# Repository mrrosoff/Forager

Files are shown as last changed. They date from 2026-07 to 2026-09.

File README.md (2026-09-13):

# Forager

A hoary marmot that lives on a shelf. It is an e-ink tamagotchi in a small
3D-printed enclosure, and it is born the first time you power it on. You keep
it alive by feeding it real Pacific Northwest species, and what it offers you
depends on the season, the month, and the actual weather in Seattle.
Chanterelles show up after an autumn rain and not in March. Neglect it for
about a week and it dies.

Most of its life is deep sleep. Press ENTER, it wakes in a couple of seconds,
redraws the panel, and drops back to sleep after two minutes of being ignored.
A charge lasts a long time because the radio almost never runs.

<p align="center">
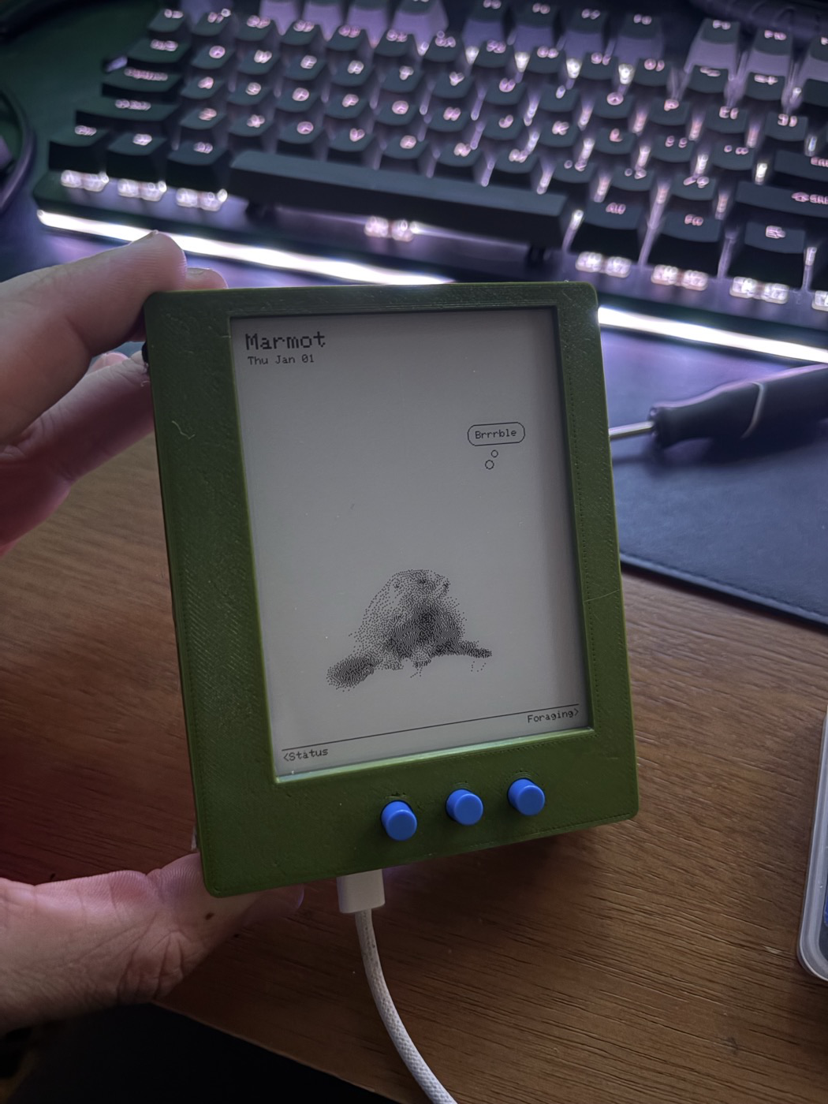
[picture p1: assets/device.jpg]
Forager: a hand-held e-ink marmot tamagotchi in a green 3D-printed enclosure
  
</p>

## Getting started

You need [PlatformIO](https://platformio.org/) and a WiFi network. Copy
`include/secrets.example.h` to `include/secrets.h` and list one or more
networks. On each sync it scans and joins whichever known network is
strongest, so you can leave both your house and your phone hotspot in there.

```cpp
static const WifiCred WIFI_NETWORKS[] = {
    {"home-ssid",  "home-pass"},
    {"phone-ssid", "hotspot-pass"},
};
```

Wire it up per the pin table in `include/config.h`, then build and flash over
the XIAO's USB-C port.

```sh
pio run              # build
pio run -t upload    # flash
pio device monitor   # serial monitor (115200)
```

esptool will claim it reset the board, but on USB-serial-JTAG it doesn't
actually start the app. Tap RESET after a flash.

There is no power switch, because the enclosure lost it. A brand new device
sits on a blank screen with its buttons armed until you press LEFT and RIGHT
together, which is the power-on gesture. That only ever happens once per
device. After that it runs the birth sequence and asks you to name the marmot.

Everything else configures itself. Weather comes from
[wttr.in](https://wttr.in/) and the clock from NTP, and neither one needs a
key.

## How it lives

**Four bars, three of them lethal.** Hunger, Happiness and Energy all decay
over roughly a week and will kill the marmot at either extreme. Curiosity is a
fourth bar that just sulks. Young marmots decay slower, which is the grace
period for figuring out what the buttons do. Every bar has something that
fills it. Eating and Snack Hunt cover Hunger, Marmot Says and resolved events
cover Happiness, Burrow Maze covers Energy, and the species games and
Discoveries cover Curiosity.

**It grows up on variety, not on time.** Baby to Juvenile to Adult is driven
by how many *distinct* species it has eaten, so a marmot fed the same
huckleberry every day stays a baby.

**Four views, LEFT and RIGHT to walk between them.** Minigames, Status, Main,
Foraging, with Main in the middle. Main is the marmot itself, along with its
mood, the weather and anything currently demanding attention. Foraging pages
through what is in season right now, sorted by what is actually worth picking,
and ENTER eats it. Status is the raw numbers for when you want to know exactly
how bad things are.

**Events happen while you're away.** Every six hours or so there's a chance
the next wake opens on a discovery, an animal sighting, a trail mishap, a
weather turn, a treasure, or an encounter, and it holds Main until you deal
with it. Playing with the thing regularly raises the odds, which is the point.

**Five minigames, all turn-based.** A panel refresh takes most of a second, so
nothing here can be scored on reflexes. Every game waits for you. Snack Hunt
and Marmot Says are there from birth, Forest Memory arrives at Juvenile,
Burrow Maze at Adult, and the Species Quiz once you've discovered 50 species.
Locked games aren't listed at all. Each one keeps a high score and gets a
one-time reveal screen when it unlocks.

**Winter is coming, specifically.** Snack Hunt's finds pile up in a stash
across days, and only the first run of each day counts, so you can't clear the
goal in one determined evening. The first December wake settles the books
against a 120-point goal. Falling short stings a little. It is not a second
way to kill the marmot.

The SETTINGS button (the one on the display module) gets you Achievements,
WiFi networks, Reset Game and Power Off.

## Hardware

| Part | Detail |
|---|---|
| MCU | Seeed XIAO ESP32S3, 8 MB flash, charges the cell over the same USB-C you flash through |
| Display | Waveshare 4.2" e-ink, 400×300 physical, mounted portrait for a 300×400 canvas |
| Buttons | 4× tactile, LEFT / RIGHT / ENTER, plus the display module's own KEY1 as SETTINGS |
| Battery | LiPo 3.7 V, soldered to BAT+/BAT- |

The XIAO breaks out exactly eleven GPIO and this needs exactly eleven, so
there is no spare and no room to change your mind. GPIO43/44 are neither
RTC-capable nor ADC, which rules them out for the three wake buttons and for
the battery divider, so they take display signals instead.

LEFT, RIGHT and ENTER are pulled down, read active-HIGH, and all three wake
the board out of deep sleep. SETTINGS rides the display board's KEY1, which is
wired to ground and therefore active-LOW, the opposite polarity from
everything else. It isn't a wake source, so Settings only exists once the
device is already awake.

One thing worth knowing before you debug the wrong end. This board will not
associate at the default 20 dBm. Scanning works fine the whole time and
reports a strong signal, because a scan only needs the receive path. Dropping
TX power to 8.5 dBm fixes it in about 1.6 seconds.

## Build, format, lint

```sh
pio run              # build
pio run -t upload    # flash
pio device monitor   # serial @ 115200

clang-format -i $(find src include -name '*.cpp' -o -name '*.h' | grep -v epd_official)
pio run -t compiledb    # then clang-tidy against src/, skipping epd_official/
```

Or just use the PlatformIO extension in VSCode, which
`.vscode/extensions.json` will offer you.

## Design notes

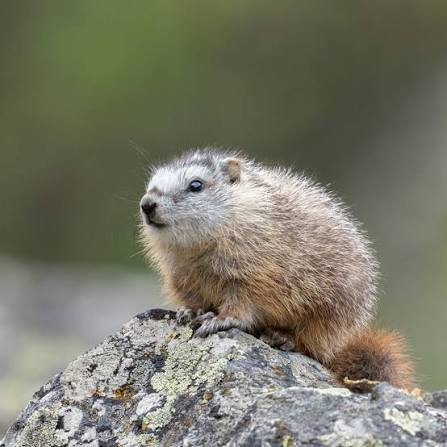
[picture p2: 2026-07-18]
assets/source_photos/marmot/juvenile3.jpg

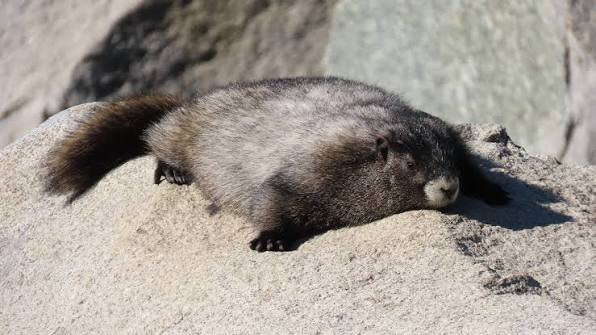
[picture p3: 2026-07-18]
assets/source_photos/marmot/variant15.jpg

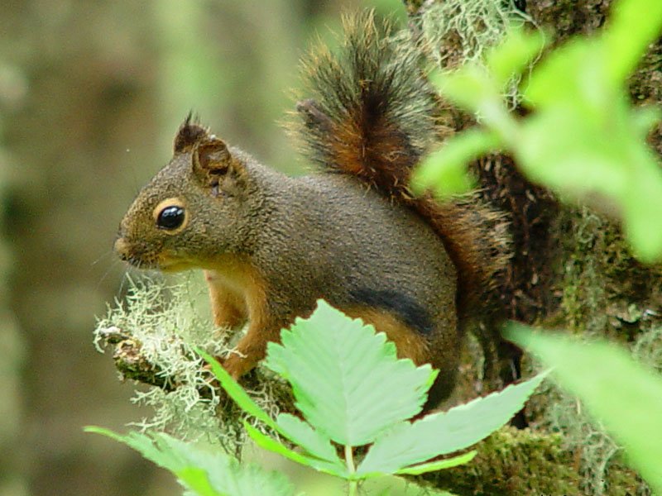
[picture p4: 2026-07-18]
assets/source_photos/animals/douglas_squirrel.jpg

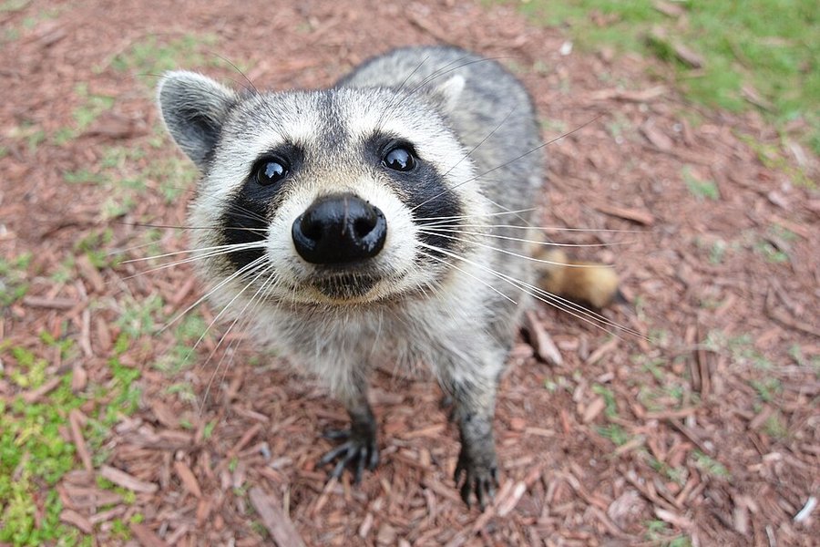
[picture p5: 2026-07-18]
assets/source_photos/animals/raccoon.jpg

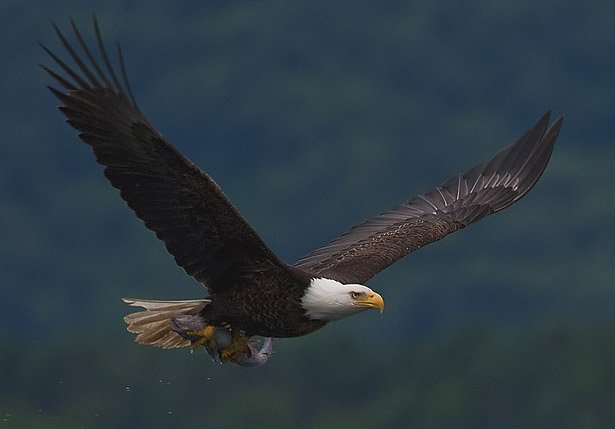
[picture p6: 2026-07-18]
assets/source_photos/animals/bald_eagle.jpg

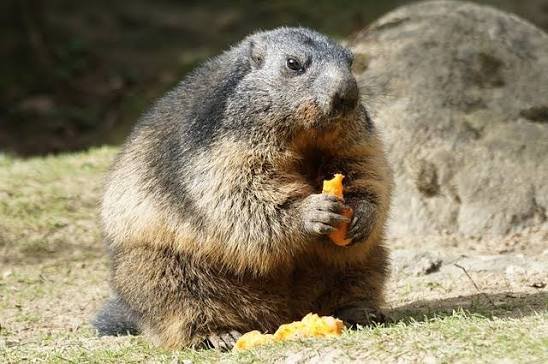
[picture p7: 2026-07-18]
assets/source_photos/marmot/variant13.jpg

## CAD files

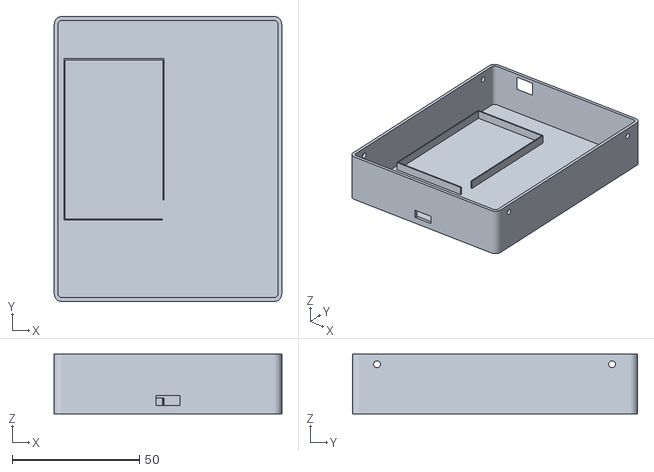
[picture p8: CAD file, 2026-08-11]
enclosure/stl/rear_tray.stl
89.5 x 112.1 x 23.5

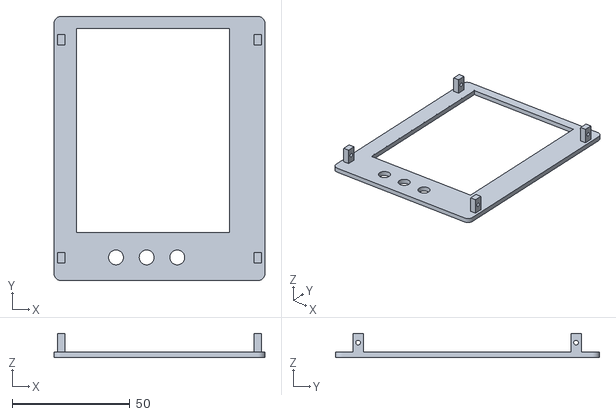
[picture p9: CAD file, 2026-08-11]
enclosure/stl/front_bezel.stl
89.5 x 112.1 x 10.4

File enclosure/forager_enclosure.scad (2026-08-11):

// Forager enclosure — 2-part (front bezel + rear tray), screwed together.
//
// PORTRAIT LAYOUT: the display PCB is physically landscape (93.5 x 78.5mm)
// but the UI renders rotated 90deg into a portrait 300x400 canvas
// (epd.setRotation(3), see CLAUDE.md). The board mounts rotated 90deg to
// match: its long 93.5mm edge runs along the case's Y axis.
//
// Hardware (measured / vendor-spec):
//   - Display: Waveshare 4.2" e-paper (GDEY042T81), PCB 93.5x78.5mm, active
//     area 84.8x63.6mm, board+FPC thickness 12.0mm.
//   - MCU: ESP32-S3 Super Mini, 22.52 x 18mm.
//   - Battery: 2000mAh LiPo pouch, 60 x 36 x 7mm.
//   - Buttons: 3x 6x6mm tactile, in the front bezel.
//   - Slide switch: 4 x 8mm (ASSUMPTION on exact part).
//
// CASE-X AXIS IS MIRRORED FROM PHYSICAL LEFT/RIGHT: confirmed against a
// real print -- physical RIGHT is case-X's low side (X near 0), physical
// LEFT is case-X's high side (X near outer_w). Keep this in mind before
// changing any *_x_lo/*_x_hi value.
//
// Render one part at a time:
//   openscad -D part=\"bezel\" -o stl/front_bezel.stl forager_enclosure.scad
//   openscad -D part=\"tray\"  -o stl/rear_tray.stl   forager_enclosure.scad
//   openscad -D part=\"both\"  -o preview/assembled.png forager_enclosure.scad
part = "both"; // "bezel" | "tray" | "both" (both = preview only, side by side)

$fn = 48;

// ---- General ----
wall      = 1.5;   // side-wall thickness (Y / top+bottom, and the X base)
clearance = 0.3;   // general fit clearance around boards
corner_r  = 3.0;   // rounded exterior corners

// Side-entry screw dimensions -- defined early since top_rim/bottom_rim
// below need side_boss_od/side_clear_d to size their bands correctly.
side_boss_od      = 4.5;  // +1mm from real-print feedback -- there was
                           // room to make the screw flanges chunkier
side_pilot_d      = 2.0;
side_clear_d      = 2.7;

// wall_x_lo/wall_x_hi: the TRAY's own side-wall thickness. Just a plain
// wall with a small pass-through clearance hole for the screw shaft -- no
// need to be any thicker than the standard `wall`.
wall_x_lo = wall;
wall_x_hi = wall;

// The screw FLANGE (the tab on the bezel side, see front_bezel()) is a
// separate feature from the tray's wall above, and floats independently in
// the tray's open cavity. flange_w is its own thickness (the screw's
// thread engagement depth) -- +1mm from real-print feedback (there was
// room), same reasoning as side_boss_od just above.
flange_w = 3.2;
// flange_inset is the case edge to the flange's near face -- flush against
// the wall (== wall thickness) rather than floating further in. v6 print
// feedback found the top screw flanges pinching the real PCB; the old
// 5.0mm inset put dead space between the wall and the flange while
// pocket_x_inset (below) was DERIVED from flange_inset, so the flange and
// the pocket always moved together and the gap between them never
// actually changed regardless of flange_inset's value. Decoupling them --
// flange flush to the wall, pocket_x_inset held fixed at its old numeric
// value independent of flange_inset -- opens up real clearance between
// the flange and the board without resizing the case at all.
flange_inset = wall;

// Case edge to pocket edge, both sides (symmetric: flange position and
// size don't differ side to side -- the bezel-width asymmetry comes
// entirely from win_margin_left/right below, the real hardware offset).
// Deliberately NOT derived from flange_inset (see above) -- this is the
// same 9.2mm the old flange_inset=5.0 formula produced, kept fixed so the
// case/pocket geometry doesn't change as flange_inset moves independently.
pocket_x_inset = 9.2;
// Actual flange-to-pocket clearance with the above two fixed: 9.2 - wall -
// flange_w = 5.5mm per side (was pinned at 2.0mm before decoupling).
flange_side_clearance = pocket_x_inset - flange_inset - flange_w;

// ---- Display module (Waveshare 4.2", GDEY042T81) ----
// Rotated 90deg from native landscape PCB layout, so disp_w/disp_h/win_w/
// win_h below are CASE-axis (X=width, Y=height), not vendor labels:
//   native disp_w (93.5, long edge)  -> case-Y (disp_h)
//   native disp_h (78.5, short edge) -> case-X (disp_w)
//   native win_w  (84.8, active long axis)  -> case-Y (win_h)
//   native win_h  (63.6, active short axis) -> case-X (win_w)
disp_w = 70.5;  // real board measured smaller than modeled, same story as disp_h below
disp_h = 90.5;  // real board measures 3mm shorter than the vendor spec
disp_t = 12.0;  // board + FPC connector bump
disp_wire_clearance = 3.0; // room behind the board for the FPC cable to bend

win_h  = 86.5;  // real measured visible screen height (was modeled too tall)
win_margin_top = (disp_h - win_h) / 2;
win_margin_bottom = win_margin_top;

// Measured from the board: a small margin on one side, a much wider one on
// the other. Case-X is mirrored from physical (see header note), so the
// wide margin lands on win_margin_right here. 0.3mm floor instead of a true
// 0 so the window cut doesn't run flush into the pocket cut.
win_margin_left  = 0.3;
win_margin_right = 5.2;
win_w = disp_w - win_margin_left - win_margin_right; // = 65.0, real measured visible screen width

// ---- MCU: ESP32-S3 Super Mini ----
mcu_w = 22.52;
mcu_l = 18.0;
mcu_component_h = 4.0; // clearance for USB-C connector / header stubs


// ---- Battery: 2000mAh LiPo, 60 x 36 x 7mm ----
batt_w = 60.0;
batt_h = 36.0;
batt_t = 7.0;
batt_puff_clearance = 2.0; // LiPo pouches puff up over time

// ---- Buttons: 3x 6x6mm tactile, in a row below the display window ----
btn_body      = 6.0;
btn_hole      = 6.3;  // counterbore the switch body presses into, from behind
btn_counterbore_depth = 1.4;
btn_cap_hole  = 3.6;  // through-hole the actuator cap pokes through
btn_pitch     = 13.0;
btn_row_gap   = 5.65;  // gap from window bottom edge to button hole centers -- centered
                       // in button_area_h (button_area_h/2)
btn_center_offset = (win_margin_left - win_margin_right) / 2; // centers the
                          // row under the WINDOW, not outer_w/2, since the
                          // window itself isn't centered (asymmetric margins)

// ---- Display module's onboard buttons (now the case's TOP edge) ----
// KEY0/KEY1 sit on the board's native RIGHT edge, FPC on the native LEFT
// edge; after rotation that's the case's TOP/BOTTOM. Only KEY1 (wired as
// PIN_BTN_SETTINGS) gets a cutout.
disp_btn_w = 6.0;
disp_btn_h = 3.5;
disp_btn_x1 = 11.03; // KEY1 -- has a cutout. Shifted 5mm toward the
                      // battery-bay wall (case-X low) from real-print
                      // feedback -- was offset from the true button
                      // position with the display centered correctly.
disp_btn_x2 = 33.70; // KEY0 -- reference only, no cutout

// top_rim/bottom_rim: bands above/below the display pocket.
//
// Only the BOTTOM pair of screws still lives up against a corner (see
// side_y_bottom/side_ys below) -- the top pair moved down to 10mm off the
// top edge (see side_y_top below), floating in the side margin next to the
// pocket rather than needing its own dedicated band, since a corner-hugging
// screw up there was costing ~4mm of bezel it didn't need to. A corner
// screw needs real clearance for two reasons:
//   - The bezel's flange sits at X=flange_inset (>= corner_r), so it's
//     safe at ANY Y as long as it doesn't touch the flat edge exactly.
//   - The TRAY's clearance hole enters right at the true exterior surface
//     (X=0), where corner_r actually matters: the case boundary near a
//     corner curves away from X=0 for any Y < corner_r, so a hole drilled
//     from X=0 at Y < corner_r isn't drilled through real wall material at
//     its outer opening -- it's carved into the curve itself.
// So side_screw_edge_clearance needs >= corner_r + the hole's own radius
// (side_clear_d/2) + a small buffer, not just side_boss_od/2. bottom_rim
// still needs to contain that. top_rim no longer hosts a screw at all, so
// it only needs to be a plain closing wall.
side_screw_edge_clearance_bottom = corner_r + side_clear_d / 2 + 0.3;
top_rim    = wall + 1.0;
bottom_rim = side_screw_edge_clearance_bottom + side_boss_od / 2 + 0.3;

// ---- USB-C access (in tray side wall, aligned to MCU edge) ----
usbc_slot_w = 9.5;
usbc_slot_h = 4.0;

// ---- Derived footprint ----
pocket_w = disp_w + 2 * clearance;
pocket_h = disp_h + 2 * clearance;

outer_w = pocket_w + 2 * pocket_x_inset; // pocket_x_inset already includes the wall
button_area_h = 11.3; // sized to hit the 20mm bottom-bezel target with the new bottom_rim
outer_h = pocket_h + bottom_rim + button_area_h + top_rim;

bezel_front_t = 2.4;   // front face thickness (button cap holes live here)
bezel_pocket_depth = disp_t + clearance + disp_wire_clearance;
bezel_total_t = bezel_front_t + bezel_pocket_depth;
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

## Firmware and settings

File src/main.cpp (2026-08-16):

#include <Arduino.h>
#include <Preferences.h>
#include <driver/rtc_io.h>

#include <algorithm>
#include <string>

#include "config.h"
#include "creature.h"
#include "display.h"
#include "events.h"
#include "foraging.h"
#include "journal.h"
#include "minigames.h"
#include "model.h"
#include "net.h"
#include "textentry.h"
#include "wifistore.h"

SET_LOOP_TASK_STACK_SIZE(16 * 1024);

static AppContext ctx;
static View currentView = View::Main;
static int forageIdx = 0;  // Foraging view's browse position; session-only, and
                           // reset to DEV_MODE_SPECIES_BROWSE_START on every
                           // transition into/out of Foraging (see
                           // retreatView()/advanceView())
static uint32_t lastActivityMs = 0;

// Set by buildContext() when the growth stage just advanced since the last
// acknowledged wake -- setup() shows display::renderTransition() and blocks
// on ENTER before continuing, if set.
static bool pendingTransition = false;
static Stage transitionToStage = Stage::Baby;

// Set by buildContext() when creature::checkDeath() reports a bar has
// bottomed out -- setup() shows display::renderDeath() and resets the
// whole game once acknowledged. None means still alive.
static DeathCause marmotDeathCause = DeathCause::None;

struct Btn {
  int pin;
  bool prev;
  uint32_t lastEdge;
  // LEFT/RIGHT/ENTER are dedicated buttons wired to 3V3 through the power
  // switch (INPUT_PULLDOWN, reads HIGH when pressed). SETTINGS instead
  // rides the e-ink display module's own onboard KEY1 button (Waveshare
  // Pico-ePaper-4.2), which is wired switch-to-GND like every Waveshare
  // board button -- INPUT_PULLUP, reads LOW when pressed.
  bool activeHigh;
};
static Btn bLeft{PIN_BTN_LEFT, false, 0, true};
static Btn bRight{PIN_BTN_RIGHT, false, 0, true};
static Btn bEnter{PIN_BTN_ENTER, false, 0, true};
static Btn bSettings{PIN_BTN_SETTINGS, false, 0, false};

/**
 * Settings overlay state (see loop()) -- not part of the View cycle, since
 * it's triggered by its own dedicated button rather than LEFT/RIGHT paging.
 * selectedOption indexes display::SETTINGS_* (Achievements, WiFi Networks,
 * Reset Game, Power Off).
 */
static bool inSettings = false;
static int selectedOption = 0;
static bool confirmPending = false;

/**
 * Achievements sub-screen (under Settings). Purely a display -- LEFT/RIGHT/
 * ENTER do nothing there, SETTINGS/KEY1 backs out to the Settings menu like
 * every other sub-screen. It used to be the leftmost View (see View in
 * model.h); it moved here when the minigames took that slot, since it's a
 * read-only progress wall rather than something you interact with.
 */
static bool inAchievements = false;

/**
 * Minigames view state (see handleMinigamesInput()). The game menu and the
 * runs themselves all live inside View::Minigames rather than being an
 * overlay -- the marmot's still on the other views the whole time.
 */
static minigames::State mg;
/**
 * Non-interactive playback frames (Marmot Says' sequence, Forest Memory's
 * look-at-both-cards beat) advance on this timer.
 *
 * 900ms was too fast: the panel spends a few hundred of those milliseconds
 * refreshing, so consecutive frames read as one continuous flicker rather
 * than as distinct calls -- and a sequence you can't visually separate is
 * one you can't memorise. 2000ms still read as rushed on real hardware, so
 * this leaves a longer, clearly still frame between flips.
 */
static const uint32_t MG_FRAME_MS = 2800;
static uint32_t mgNextFrameMs = 0;
// A finished run tops the marmot up at most once per wake (see
// creature::rewardMinigame()) -- otherwise replaying a good run is a
// happiness faucet.
static bool minigameRewarded = false;

/**
 * WiFi Networks sub-screen state (under Settings -- see handleWifiMenuInput()).
 * wifiSelected indexes wifistore -- an index == wifistore::count() means the
 * trailing "Add Network" row is selected.
 */
static bool inWifiMenu = false;
static int wifiSelected = 0;
static bool wifiRemoveConfirm = false;

/**
 * Shared text-entry overlay (see textentry.h) -- drives marmot naming and
 * WiFi SSID/password entry through the same LEFT/RIGHT-scroll,
 * ENTER-commits picker. tePurpose says what happens when DONE is picked;
 * None means the overlay isn't active.
 */
enum class TextEntryPurpose { None, MarmotName, WifiSsid, WifiPassword };
static TextEntryPurpose tePurpose = TextEntryPurpose::None;
static textentry::State teState;
static std::string pendingWifiSsid;  // holds the SSID while its password is typed next

// Accelerating hold-to-scroll state for RIGHT on the Foraging view (see
// loop()): a held press repeats faster the longer it's held, down to a
// floor, rather than a fixed step size.
static bool rightHeld = false;
static uint32_t rightNextStepMs = 0;
static int rightHoldSteps = 0;
static const uint32_t RIGHT_HOLD_INITIAL_MS = 350;
static const uint32_t RIGHT_HOLD_FLOOR_MS = 20;
static const uint32_t RIGHT_HOLD_ACCEL_MS = 60;

// Same accelerating hold-to-scroll shape as Foraging's RIGHT above, factored
// out so other views can reuse it without their own copy of the state
// machine. Returns true once per step that should fire: immediately on a
// fresh press, then repeatedly with a shrinking interval (down to `floorMs`)
// while held. Takes its own curve rather than sharing Foraging's
// RIGHT_HOLD_* constants -- a redraw-bound context (like the text-entry
// keyboard, which measures every key's text bounds on every frame, unlike
// Foraging's simpler card) can saturate at "however fast the panel
// physically redraws" well before a 20ms floor is ever reached, making the
// ramp invisible; a higher floor keeps the whole curve inside a range where
// speeding up is actually perceptible against that redraw cost.
struct HoldAccel {
  bool held = false;
  uint32_t nextStepMs = 0;
  int steps = 0;
};

static bool holdAccelStep(HoldAccel& s, bool down, uint32_t initialMs, uint32_t floorMs,
                          uint32_t accelMs) {
  if (down && !s.held) {
    s.held = true;
    s.steps = 0;
    s.nextStepMs = millis() + initialMs;
    return true;
  }
  if (down && s.held && millis() >= s.nextStepMs) {
    s.steps++;
    uint32_t interval =
        initialMs > (uint32_t)s.steps * accelMs ? initialMs - s.steps * accelMs : floorMs;
    if (interval < floorMs) interval = floorMs;
    s.nextStepMs = millis() + interval;
    return true;
  }
  if (!down) s.held = false;
  return false;
}

// Text-entry's keyboard redraw is heavier than Foraging's card (measures
// every key's text bounds every frame), so it needs a slower ramp and a
// much higher floor -- see HoldAccel's doc comment above.
static const uint32_t TE_HOLD_INITIAL_MS = 400;
static const uint32_t TE_HOLD_FLOOR_MS = 150;
static const uint32_t TE_HOLD_ACCEL_MS = 25;

/**
 * Tops up time and weather on the way out, after the sleep screen is already
 * drawn and the player has walked away -- the radio costs ~17s, and this is
 * the one moment nobody is waiting on the panel. Skipped entirely while the
 * cache is fresh, so most sleeps never power the radio at all.
 */
static void refreshNetworkBeforeSleep() {
  time_t now = time(nullptr);
  // Banked every sleep, so a power-cycle resumes from here rather than 1970.
  net::rememberClock();
  if (!net::refreshDue(now)) return;
  if (!net::connectStrongest()) {
    net::shutdown();
    return;
  }
  struct tm discard;
  net::syncTime(discard);
  net::saveWeather(net::fetchWeather());
  net::shutdown();
}

/**
 * Arms the three buttons as ext1 wake sources. ext1 (not ext0) so all three
 * wake the board -- ext0 only supports a single GPIO -- with ANY_HIGH, since
 * they read HIGH when pressed (INPUT_PULLDOWN).
 *
 * The RTC pulldowns are not optional: pinMode()'s INPUT_PULLDOWN is a digital
 * IO-mux pull, and that block is powered down in deep sleep, which leaves
 * these three floating under ANY_HIGH. Floating was enough for body
 * capacitance to trip a wake just from picking the device up.
 */
static void armButtonWake() {
  const int wakePins[] = {PIN_BTN_LEFT, PIN_BTN_RIGHT, PIN_BTN_ENTER};
  uint64_t wakeMask = 0;
  for (int pin : wakePins) {
    rtc_gpio_pullup_dis((gpio_num_t)pin);
    rtc_gpio_pulldown_en((gpio_num_t)pin);
    wakeMask |= 1ULL << pin;
  }
  esp_sleep_enable_ext1_wakeup(wakeMask, ESP_EXT1_WAKEUP_ANY_HIGH);
}

RTC_DATA_ATTR static bool rtcParked = false;

// Persisted, so the combo is asked for once in the device's life and not
// again after every flash or power cycle.
static bool everTurnedOn() {
  Preferences p;
  p.begin("forager", /*readOnly=*/true);
  bool on = p.getBool("poweredOn", false);
  p.end();
  return on;
}

static void markTurnedOn() {
  Preferences p;
  p.begin("forager", /*readOnly=*/false);
  p.putBool("poweredOn", true);
  p.end();
}

/**
 * Parks: blank panel, buttons armed, and rtcParked set so the next wake
 * demands the LEFT+RIGHT combo. Never returns.
 */
static void enterParked() {
  rtcParked = true;
  display::renderPowerOff();  // blank frame
  display::hibernate();
  armButtonWake();
  esp_deep_sleep_start();
}

/** True if LEFT and RIGHT are held together at any point within the window. */
static bool powerComboHeld() {
  uint32_t start = millis();
  while (millis() - start < POWER_COMBO_WINDOW_MS) {
    if (digitalRead(PIN_BTN_LEFT) == HIGH && digitalRead(PIN_BTN_RIGHT) == HIGH) {
      return true;
    }
    delay(10);
  }
  return false;
}

/**
 * Gate for waking out of the parked state. ext1 on the S3 only offers
 * ANY_HIGH, so any single button wakes the board -- the combo has to be
 * checked here instead, and a wake that fails it goes straight back to
 * sleep. Runs before display::begin(), so a rejected press costs no panel
 * refresh and is invisible.
 */
static void gatePowerCombo() {
#if !DEV_MODE_NO_SLEEP
  if (!rtcParked) return;
  if (powerComboHeld()) {
    rtcParked = false;
    markTurnedOn();
    return;
  }
  armButtonWake();
  esp_deep_sleep_start();
#endif
}

/**
 * Parks on the very first power-up ever, so a new device waits to be turned
 * on rather than waking the marmot whenever the cell went in. Later
 * power-ups, flashes and brownouts boot straight through -- being asked for
 * the combo every time was worse than the problem it solved.
 */
static void parkUntilFirstPress() {
#if !DEV_MODE_NO_SLEEP
  if (esp_sleep_get_wakeup_cause() != ESP_SLEEP_WAKEUP_UNDEFINED) return;
  if (everTurnedOn()) return;
  enterParked();
#endif
}

static void goToSleep() {
#if DEV_MODE_NO_SLEEP
  return;
#else
  // Always return to Main next wake, and show the sleeping marmot now --
  // the bistable e-ink panel keeps displaying whatever we draw here,
  // unpowered, until the next wake redraws it.
  currentView = View::Main;
  display::renderSleep((Stage)ctx.stage);
  refreshNetworkBeforeSleep();
  display::hibernate();
  armButtonWake();
  esp_sleep_enable_timer_wakeup(FORCE_REFRESH_INTERVAL_US);
  esp_deep_sleep_start();
#endif
}

/**
 * Settings -> Power Off: parks exactly like a fresh power-up, so LEFT+RIGHT
 * turns it back on. It used to arm no wake source at all, recoverable only
 * via the inline power switch -- which no longer exists, so that version
 * would have been a one-way trip.
 */
static void doPowerOff() {
  enterParked();
}

/**
 * Settings -> Reset Game (confirmed): wipes the single "forager" NVS
 * namespace -- creature state, event cooldown, and the journal all live
 * there (see the module-level Preferences usage in creature.cpp/events.cpp/
 * journal.cpp), so one clear() resets everything at once -- then reboots
 * straight into the first-ever-boot path, triggering the birth sequence.
 */
static void doResetGame() {
  // The WiFi list shares the namespace but isn't game state -- wiping it would
  // lose the networks the player set up and hand them back whatever secrets.h
  // was compiled with.
  wifistore::load();
  bool wasOn = everTurnedOn();  // device setup, not game state -- same as WiFi
  Preferences p;
  p.begin("forager", /*readOnly=*/false);
  p.clear();
  p.end();
  wifistore::persist();
  if (wasOn) markTurnedOn();
  esp_restart();
}

/**
 * Battery volts off the divider. The 2x200k pair leaves ~100k of source
 * impedance at the tap, well above the ~10k the ESP32 ADC wants, so a single
 * conversion reads low -- the sample-and-hold cap can't charge inside one
 * sampling window. Repeated conversions let it settle, and the first is
 * thrown away. analogReadMilliVolts() applies the factory ADC calibration,
 * so this is real millivolts rather than a raw count.
 */
static float readBatteryVolts() {
  analogReadMilliVolts(PIN_BATT_ADC);  // discard: first read after idle is low
  // Median over mean to drop outliers, with a gap so the sample-and-hold cap
  // can recharge through 100k.
  const int kSamples = 15;
  uint32_t mv[kSamples];
  for (int i = 0; i < kSamples; i++) {
    mv[i] = analogReadMilliVolts(PIN_BATT_ADC);
    delayMicroseconds(200);
  }
  std::sort(mv, mv + kSamples);
  return (mv[kSamples / 2] / 1000.0f) * BATT_DIVIDER_RATIO;
}

/**
 * A LiPo sits between 3.7V and 3.9V for most of its capacity, so mapping
 * 3.3-4.2V linearly badly overstated the middle -- 3.7V read as 44% when the
 * cell is nearly flat, which is how a "67%" marmot died with no warning.
 * Piecewise curve, interpolated between points.
 */
static uint8_t percentForVolts(float v) {
  static const struct {
    float volts;
    uint8_t pct;
  } kCurve[] = {
      {4.20f, 100}, {4.10f, 90}, {4.00f, 80}, {3.95f, 70}, {3.90f, 60}, {3.86f, 50},
      {3.83f, 40},  {3.80f, 30}, {3.76f, 20}, {3.71f, 10}, {3.63f, 5},  {3.30f, 0},
  };
  const int n = sizeof(kCurve) / sizeof(kCurve[0]);
  if (v >= kCurve[0].volts) return 100;
  for (int i = 1; i < n; i++) {
    if (v < kCurve[i].volts) continue;
    float span = kCurve[i - 1].volts - kCurve[i].volts;
    float frac = span > 0.0f ? (v - kCurve[i].volts) / span : 0.0f;
    return (uint8_t)(kCurve[i].pct + frac * (kCurve[i - 1].pct - kCurve[i].pct) + 0.5f);
  }
  return 0;
}

// Set once the cutoff has drawn its screen, so a recheck wake that still
// reads low can skip the panel.
RTC_DATA_ATTR static bool rtcLowBattery = false;

/**
 * Parks on a flat cell, returning only if the cell is fine. Arms the buttons
 * and a periodic recheck rather than no wake source at all -- the device has
 * to be able to notice it has been charged.
 */
static void parkIfBatteryFlat() {
  float v = readBatteryVolts();
  if (v >= BATT_CUTOFF_VOLTS) {
    rtcLowBattery = false;
    return;
  }
  // Confirm before parking: a cell dies slowly, but one marginal sample
  // parking the device means a trip to the RESET button.
  delay(750);
  float v2 = readBatteryVolts();
  log_i("Battery cutoff check: %.3fV then %.3fV (cutoff %.2fV, parked %d)", v, v2,
        BATT_CUTOFF_VOLTS, (int)rtcLowBattery);
  if (v2 >= BATT_CUTOFF_VOLTS || v2 < BATT_SENSE_FAULT_VOLTS) {
    rtcLowBattery = false;
    return;
  }
  if (!rtcLowBattery) {
    creature::load(ctx.creature);  // for the stage-appropriate sleeping pose
    display::begin();
    display::renderLowBattery((Stage)ctx.creature.lastSeenStage);
    display::hibernate();
    rtcLowBattery = true;
  }
  armButtonWake();
  esp_sleep_enable_timer_wakeup(BATT_RECHECK_INTERVAL_US);
  esp_deep_sleep_start();
}

static uint8_t readBatteryPercent() {
  float v = readBatteryVolts();
  // A broken sense line reads low and steady, which would report as 0%.
  if (v < BATT_SENSE_FAULT_VOLTS) {
    log_i("Battery: %.3fV -- sense line looks broken, reporting unknown", v);
    return BATT_PERCENT_UNKNOWN;
  }
  uint8_t pct = percentForVolts(v);
  // Logged so the reading can be checked against a multimeter on the cell.
  log_i("Battery: %.3fV -> %u%%", v, pct);
  return pct;
}
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
void loop() {
  if (tePurpose != TextEntryPurpose::None) {
    handleTextEntryInput();
    lastActivityMs = millis();
  } else if (pressed(bSettings)) {
    // SETTINGS/KEY1 is "back" at whatever depth we're currently at, one
    // level per press -- confirm sub-screen -> its parent menu -> Settings
    // itself -> exit Settings entirely. Pressing it from outside Settings
    // enters it fresh, same as before -- except mid-minigame, where the
    // run itself is the thing to back out of first.
    if (!inSettings && currentView == View::Minigames && mg.screen != minigames::Screen::Menu) {
      mg.screen = minigames::Screen::Menu;
      renderCurrent();
    } else if (!inSettings) {
      inSettings = true;
      selectedOption = 0;
      confirmPending = false;
      display::renderSettings(selectedOption, confirmPending, ctx.batteryPercent);
    } else if (inAchievements) {
      inAchievements = false;
      display::renderSettings(selectedOption, false, ctx.batteryPercent);
    } else if (inWifiMenu) {
      if (wifiRemoveConfirm) {
        wifiRemoveConfirm = false;
        display::renderWifiMenu(wifiSelected, false);
      } else {
        inWifiMenu = false;
        display::renderSettings(selectedOption, false, ctx.batteryPercent);
      }
    } else if (confirmPending) {
      confirmPending = false;
      display::renderSettings(selectedOption, confirmPending, ctx.batteryPercent);
    } else {
      inSettings = false;
      renderCurrent();
    }
    lastActivityMs = millis();
  } else if (inAchievements) {
    // Read-only wall -- LEFT/RIGHT/ENTER do nothing here, BACK is the only
    // way out (handled above). Still drain their edge state so a press held
    // through the transition doesn't fire once we're back in a menu.
    pressed(bLeft);
    pressed(bRight);
    pressed(bEnter);
  } else if (inWifiMenu) {
    handleWifiMenuInput();
    lastActivityMs = millis();
  } else if (inSettings) {
    handleSettingsInput();
    lastActivityMs = millis();
  } else if (currentView == View::Minigames) {
    if (handleMinigamesInput()) lastActivityMs = millis();
  } else {
    if (pressed(bLeft)) {
      retreatView();
      lastActivityMs = millis();
    }
    if (currentView == View::Foraging) {
      // Accelerating hold-to-scroll: a fresh press steps once immediately;
      // holding repeats with a shrinking interval down to a floor, and each
      // repeat's jump size grows (see forageHoldStepSize()) since the panel's
      // own redraw time -- not the repeat interval -- is what actually
      // bounds how fast this can go.
      bool rightDown = digitalRead(PIN_BTN_RIGHT) == HIGH;
      if (rightDown && !rightHeld) {
        rightHeld = true;
        rightHoldSteps = 0;
        advanceForageIdx();
        rightNextStepMs = millis() + RIGHT_HOLD_INITIAL_MS;
        lastActivityMs = millis();
      } else if (rightDown && rightHeld && millis() >= rightNextStepMs) {
        rightHoldSteps++;
        uint32_t interval = RIGHT_HOLD_INITIAL_MS > rightHoldSteps * RIGHT_HOLD_ACCEL_MS
                                ? RIGHT_HOLD_INITIAL_MS - rightHoldSteps * RIGHT_HOLD_ACCEL_MS
                                : RIGHT_HOLD_FLOOR_MS;
        if (interval < RIGHT_HOLD_FLOOR_MS) interval = RIGHT_HOLD_FLOOR_MS;
        advanceForageIdx(forageHoldStepSize(rightHoldSteps));
        rightNextStepMs = millis() + interval;
        lastActivityMs = millis();
      } else if (!rightDown) {
        rightHeld = false;
      }
      bRight.prev = rightDown;
    } else if (pressed(bRight)) {
      advanceView();
      lastActivityMs = millis();
    }
    if (pressed(bEnter)) {
      onEnter();
      lastActivityMs = millis();
    }
  }

#if DEV_MODE_NO_SLEEP
  static int lastLeft = -1, lastRight = -1, lastEnter = -1, lastSettings = -1;
  int left = digitalRead(PIN_BTN_LEFT);
  int right = digitalRead(PIN_BTN_RIGHT);
  int enter = digitalRead(PIN_BTN_ENTER);
  int settings = digitalRead(PIN_BTN_SETTINGS);
  if (left != lastLeft) {
    log_i("LEFT  (GPIO%d) = %d", PIN_BTN_LEFT, left);
    lastLeft = left;
  }
  if (right != lastRight) {
    log_i("RIGHT (GPIO%d) = %d", PIN_BTN_RIGHT, right);
    lastRight = right;
  }
  if (enter != lastEnter) {
    log_i("ENTER (GPIO%d) = %d", PIN_BTN_ENTER, enter);
    lastEnter = enter;
  }
  if (settings != lastSettings) {
    log_i("SETTINGS (GPIO%d) = %d (active-low: 0 = pressed)", PIN_BTN_SETTINGS, settings);
    lastSettings = settings;
  }
#endif

  // A run in progress gets the longer window (see MINIGAME_IDLE_SLEEP_MS):
  // its state is RAM-only, so sleeping mid-run throws the run away.
  bool inRun = currentView == View::Minigames && mg.screen != minigames::Screen::Menu;
  uint32_t idleWindow = inRun ? MINIGAME_IDLE_SLEEP_MS : INACTIVITY_SLEEP_MS;

  static bool loggedIdle = false;
  if (millis() - lastActivityMs > idleWindow) {
    if (!loggedIdle) {
      log_i("Idle; sleeping");
      loggedIdle = true;
    }
    goToSleep();
  } else {
    loggedIdle = false;
  }

  delay(15);
}

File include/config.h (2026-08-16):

// config.h — hardware pin map and behavioral tunables. Secrets live in secrets.h.
#pragma once

#include <Arduino.h>

// Match your panel: newer GDEY042T81 (fast partial refresh) vs older GDEW042T2.
// Currently unused by the epd_official driver (src/epd_official/), which only
// supports the GDEY042T81 revision; kept as documentation of the assumption.
#define EPD_PANEL_GDEY042T81 1

// Dev flags -- all ship at 0. CLAUDE.md's "Dev-mode flags" section covers
// what each one does to the rest of the system, including the surprises
// (SKIP_GROWTH also unlocks Adult-only events; UNLOCK_MINIGAMES doesn't
// touch the unlock reveals; EVENT_CYCLE strips the real setup()/loop()).
#define DEV_MODE_NO_SLEEP 0            // never deep-sleep; stay on USB serial
#define DEV_MODE_SKIP_GROWTH 0         // computeStage() always returns Adult
#define DEV_MODE_UNLOCK_MINIGAMES 0    // every game playable, ignoring the ladder
#define DEV_MODE_SHOW_ALL_CONTENT 0    // deal every bush/card instead of rolling
#define DEV_MODE_UNLOCK_SPECIES 0      // every species discovered, for browsing
#define DEV_MODE_ALPHABETIZE_BROWSE 0  // browse A-Z instead of by relevance
#define DEV_MODE_SPECIES_BROWSE_START 0  // 0-based start index for that browse
#define DEV_MODE_EVENT_CYCLE 0         // loop every event screen for proofreading

// GPIO numbers, not the XIAO's silkscreen D-numbers (D8 is GPIO7). DC/BUSY
// take GPIO43/44, the only pads that are neither RTC nor ADC.
static const int PIN_EPD_SCK = 7;    // yellow  (pad D8)
static const int PIN_EPD_MOSI = 9;   // blue    (pad D10, "DIN")
static const int PIN_EPD_CS = 8;     // orange  (pad D9)
static const int PIN_EPD_DC = 43;    // green   (pad D6)
static const int PIN_EPD_RST = 4;    // white   (pad D3)
static const int PIN_EPD_BUSY = 44;  // purple  (pad D7)

static const int EPD_WIDTH = 400;
static const int EPD_HEIGHT = 300;

// Wired to 3V3 through the switch, INPUT_PULLDOWN: pressed == HIGH. All three
// wake from deep sleep, so all three need RTC-capable GPIOs (0-21 on the S3).
static const int PIN_BTN_LEFT = 1;   // pad D0
static const int PIN_BTN_ENTER = 2;  // pad D1
// GPIO3 is a strapping pin, safe here: INPUT_PULLDOWN sits low at reset.
static const int PIN_BTN_RIGHT = 3;  // pad D2

// The display board's onboard KEY1 (the one the enclosure cuts a hole for),
// wired switch-to-GND: INPUT_PULLUP, active LOW, unlike the other three.
static const int PIN_BTN_SETTINGS = 5;  // pad D4

/**
 * Battery sense -- a 200k/200k divider from BAT+ to GND, tapped into GPIO6
 * (ADC1, so unaffected by the radio conflict that rules out GPIO11-20; not a
 * strapping pin). Halves the cell, so 4.2V full sits at 2.1V, inside the
 * ADC's usable range.
 *
 * 400k total also means ~100k of source impedance at the tap, well above the
 * ~10k the ADC wants -- readBatteryVolts() oversamples to compensate. The
 * voltage-to-percent curve lives there too, since a LiPo is nowhere near
 * linear.
 */
static const int PIN_BATT_ADC = 6;
static const float BATT_DIVIDER_RATIO = 2.0f;

/**
 * Below this the device parks itself: it draws a "charge me" screen and deep
 * sleeps with no wake source, so nothing can wake it to drain further. Only
 * charging revives it.
 *
 * Deliberately well above a LiPo's ~3.0V damage threshold, because the ADC
 * reads a little low through the 400k divider and it's better to park early
 * than to run a cell flat. Doing that once is what preceded the first board's
 * battery path failing.
 */
static const float BATT_CUTOFF_VOLTS = 3.40f;

// Below this the sense line is assumed broken rather than the cell flat --
// the chip browns out long before a cell reads this low, so running code
// can't really be seeing it. A floating GPIO6 (the D5 wire came off once)
// looks identical to a dead battery otherwise.
static const float BATT_SENSE_FAULT_VOLTS = 2.60f;

// How often a device parked on a flat cell wakes to re-read the battery.
static const uint64_t BATT_RECHECK_INTERVAL_US = 10ULL * 60 * 1000000ULL;

// Window to get LEFT+RIGHT held together when waking from parked. Generous on
// purpose -- it's a tolerance for pressing them slightly apart, not a reflex test.
static const uint32_t POWER_COMBO_WINDOW_MS = 1500;

static const uint32_t INACTIVITY_SLEEP_MS = 120UL * 1000UL;

// Longer window mid-run: run state is RAM-only, so sleeping over a 7x7 maze
// throws the run away. Only applies between a run's first and last press.
static const uint32_t MINIGAME_IDLE_SLEEP_MS = 300UL * 1000UL;

// Younger than this at winter and the stash screen is skipped entirely, not
// just its penalty (that's minigames::WINTER_GRACE_DAYS) -- a marmot born
// days ago shouldn't open with a "you failed to stockpile" ceremony.
static const int WINTER_TOO_YOUNG_DAYS = 7;
static const uint32_t BTN_DEBOUNCE_MS = 40;
static const uint32_t WIFI_TIMEOUT_MS = 12UL * 1000UL;
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

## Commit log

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2026-07-18 Clean up the Main view's creature rendering
    Removed redundant ground drawing, the doubled mood circle, the brow-accent circle, the eye/nose overlay, the mood-name/foraged-days text, and the sparkle-drift dots -- paring the view down to the marmot bitmap itself -- while restoring LEFT nav and manual feed, and adding a dedicated Hungry-mood bitmap.
    [config.h, main.cpp]
2026-07-18 Curate the species and animal rosters, clean up the repo
    Trimmed to 250 species with relevance-sorted browsing, a +10 skip, and category-gated foraging events; trimmed animal sightings from 34 to 25; removed scratch/unused dirs and stopped tracking editor config.
    [foraging.cpp, main.cpp]
2026-07-18 Replace procedural sprites with a real-photo art pipeline
    Sourced real photo bitmaps for animal sightings (all 25/25) and species (all 250/250), added real marmot pose variants that rotate per wake, wired them into the Foraging view and encounters, removed the procedural sprite system, reorganized bitmap headers into bitmaps/{animals,marmot}/, dropped the moon-phase module and Glowing mood, and added the sleeping-marmot pre-sleep screen.
    [foraging.cpp, main.cpp]
2026-07-18 Add growth stages, achievements, and settings; real baby/juvenile art
    Let the player eat any species to feed the marmot directly, added growth stages with baby events and a settings screen, replaced the reused-adult-pose fallback with real baby/juvenile marmot art, and rewrote README/CLAUDE.md to match.
    [config.h, foraging.cpp, main.cpp]
2026-07-18 Round out events, fix a battery drain, overhaul the art pipeline again
    Added 2 more event types and stage-transition screens, locked Achievements until Adult, fixed a battery-draining acknowledgment loop and added boredom decay with a neglect consequence, then overhauled the art pipeline (background removal, real photos) and added the naming/WiFi settings keyboard, followed by another art-fix pass.
    [config.h, main.cpp]
2026-07-18 Add growth-based discovery, energy/death, and fix hardware hangs
    Added growth-based species discovery, achievement badges, an energy/death system, and a settings UI overhaul; added a mid-session event trigger and stage-aware sleep art, and split mega-files into data/logic headers; fixed a panel-hang freeze and rotated the enclosure to portrait using real hardware measurements; fixed a device hang caused by a forced full refresh re-initializing SPI twice; tuned Discovery odds (guaranteed for Baby/Juvenile, 60% for Adult).
    [forager_enclosure.scad, front_bezel.stl, rear_tray.stl]
2026-07-18 Iteratively fix species icon art quality across the whole roster
    A long iterative pass isolating species icon subjects from their backgrounds with GrabCut segmentation, fixing dither texture and readability regressions, re-sourcing or replacing species whose photos never yielded usable art, and fixing background/quality on the ones that kept their original subject -- alongside dev-mode unlock/sort flags, enclosure geometry fixes, and scroll refresh handling.
    [forager_enclosure.scad, front_bezel.stl, rear_tray.stl]
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2026-07-18 Fix front bezel's thin pocket lip and rear tray's tiny KEY1 hole
    Front bezel: the raised display-pocket lip was fighting a redundant
    full-footprint pocket-recess cut in a coincident-face boolean, which
    CGAL resolved into a near-zero-thickness sliver instead of cleanly
    canceling -- read as fragile paper-thin walls on the print. Removed
    the separate raised-lip structure entirely; the front face slab alone
    already retains the display, since the window is narrower than the
    pocket and the slab's own material between them does the catching.
    Rear tray: KEY1's access hole was a 2.2mm placeholder sized for a bare
    switch actuator, not a fingertip. Enlarged to 6mm (the largest size
    that fits the tray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
    [forager_enclosure.scad, front_bezel.stl, rear_tray.stl]
2026-07-19 Fix enclosure fit from real-print feedback: USB-C, switch, battery, MCU, window, fasteners
    Round of fixes after test-printing and dry-fitting real hardware:
    - USB-C slot anchored to the MCU's actual mounting height instead of a
    floating centered guess
    - Slide switch gets a containment pocket sized to its real (deeper than
    assumed) body so it sits flush instead of protruding
    - MCU footprint corrected to centered + rotated 90deg with a retaining
    wall, matching the real board's orientation and position
    - Battery bay rotated 90deg to match the real pouch's orientation, shifted
    left and down to dodge display-PCB components
    - Tray interior deepened for the display's pin-header/FPC assembly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
    [forager_enclosure.scad, front_bezel.stl, rear_tray.stl]
2026-07-20 Enclosure v3: side-entry top screws, real display margin, component repositioning
    Replaced the top-center snap-fit (didn't hold) with 2 horizontal
    side-entry screws through the tray walls into bezel flanges, clear of the
    display pocket regardless of Y. Corrected the corner screws' countersink
    to the back (tray-facing) face instead of the front.
    Display window's left/right margin set from a real measurement on the
    board (~8mm one side, ~0mm the other) instead of a guessed/symmetric
    split, with the button row re-centered under the window to match. KEY1's
    hole rotated 90deg and shrunk to match its real actuator.
    ESP32: dropped the never-fitting retaining wall for 2 standoffs at the top
    of the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
    [forager_enclosure.scad, front_bezel.stl, rear_tray.stl]
2026-07-22 Enclosure v4: widen bezel/tab clearance, rework corner-clearance fix, retune buttons/screws/MCU, simplify README
    - Fixed the real driver of the corner-clearance issue: side-entry screw
    flanges only need X >= corner_r+1mm to clear the rounded corner
    regardless of Y, so top_rim/bottom_rim came back down from 14.5mm to
    8mm instead of padding case height. wall_extra_x_hi bumped slightly to
    hold that margin on both sides.
    - Widened the display pocket inset (pocket_x_inset) so the side-entry
    flanges have real clearance beside the board instead of colliding with
    it -- the root cause of a v3 fit failure.
    - Corrected disp_h to the real measured board length (93.5 -> 90.5mm),
    which shrin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
    [forager_enclosure.scad, front_bezel.stl, rear_tray.stl]
2026-07-22 Move MCU standoff/USB-C to the battery side of the rear tray
    mcu_usbc_x_center had drifted to the opposite (case-X high) side across
    several earlier "move left" edits, landing it far from the battery.
    Moved it back to the battery side (case-X low) at outer_w*0.25.
    [forager_enclosure.scad, rear_tray.stl]
2026-07-22 Enclosure v5: real bezel measurements, corner-clearance fix, screw repositioning
    - Corrected the real visible-screen size (65 x 86.5mm, was modeled as
    70.2 x 90mm) after pushing the physical display+bezel to the top-left
    corner and measuring the resulting gaps. disp_w corrected to 70.5mm to
    match (mirrors the earlier disp_h fix).
    - Decoupled the screw flange's position from the tray's own wall
    thickness: the flange floats independently in the tray's open cavity at
    a fixed 5mm inset, so the tray wall itself no longer needs to be
    artificially thick just to give the flange corner clearance. Tray
    perimeter wall (and general outer wall thickness) dropped to 1.5mm; the
    flange itsel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
    [forager_enclosure.scad, front_bezel.stl, rear_tray.stl]
2026-07-22 Fix switch opening dimensions: 9 x 4.5mm (were swapped)
    sw_slot_w/sw_slot_h had the 0.5mm reduction applied to the wrong axis.
    Corrected to 9.0 x 4.5mm; containment wall margins follow automatically.
    [forager_enclosure.scad, rear_tray.stl]
2026-07-23 Enclosure v5: real-print fit fixes -- battery wire gap, KEY1 taper, flange clearance, MCU/USBC/button repositioning
    - Battery bay: cut a wire-exit gap flush with the bottom corner of the
    wall facing the switch/MCU standoff.
    - Reduced mcu_standoff_h 3.5 -> 3.25mm.
    - KEY1 access hole: tapered/funneled from a wide 12x7mm exterior opening
    down to the exact button footprint, since the old straight hole was too
    small to get a finger into.
    - Screw flanges moved flush against the tray wall (flange_inset = wall)
    and decoupled pocket_x_inset from flange_inset, opening real clearance
    between the flanges and the real Waveshare PCB (which the top pair was
    pinching) without resizing the case.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
    [forager_enclosure.scad, front_bezel.stl, rear_tray.stl]
2026-07-24 Enclosure v6: KEY1 press feel, chunkier flanges, bottom screw off the curve
    - KEY1 access hole: oversized the inner throat too (was pinched down to
    the exact button footprint right at KEY1, now +3mm each dimension),
    not just the outer funnel mouth -- the switch is side-actuated so the
    extra margin around it is free.
    - Screw flanges made chunkier in both axes: side_boss_od 3.5 -> 4.5mm,
    flange_w 2.2 -> 3.2mm. Verified against the real Waveshare PCB width
    (78.5mm) that the flange-to-flange clear span still clears it.
    - Moved KEY1's hole 5mm toward the battery-bay wall to match the real
    button position with the display centered correctly.
    - Moved the bottom side-entry screw 5mm furt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
    [forager_enclosure.scad, front_bezel.stl, rear_tray.stl]
2026-07-27 Enclosure v7: tray walls +8mm, fix KEY1 Z drift from that change
    - Tray perimeter walls (and interior cavity, since they share one
    extrude) grown 8mm taller from real-print feedback.
    - KEY1's access hole Z position was computed as tray_wall_h/2 + 1.75
    (center-relative), which silently drifted 3mm off its real-world
    position when tray_wall_h grew for the above change. Anchored it to a
    fixed 7.0mm offset from the top (bezel-mating face) instead, so it's
    no longer coupled to unrelated cavity-depth changes.
    [forager_enclosure.scad, front_bezel.stl, rear_tray.stl]
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2026-07-28 C++ify string handling: std::string over const char* where strings are built or owned
    Converts genuinely temporary/assembled strings (nav bar labels, season
    ranges, on-screen keyboard labels, progress/streak lines, text-entry
    buffer, weather condition) from manual char buffers + snprintf/strncpy
    to std::string. Leaves const char* for static literal tables, NVS
    raw-blob-serialized fields (wifistore::Network), and fixed
    Preferences-API-bound buffers (CreatureState::name) where a std::string
    would add heap churn or break persistence without any real benefit.
    [main.cpp]
2026-07-29 Flip all dev-mode flags off for real gameplay/shipping
    [config.h]
2026-07-29 Fix birth flow resuming after power loss mid-naming; move battery icon to top-right corner
    CreatureState gains a persisted `named` flag, separate from birthDate.
    birthDate is still stamped/persisted immediately on first boot (so growth
    timing starts at the true creation moment), but firstBoot is now driven by
    `named` -- previously, losing power during the birth reveal or naming
    entry left birthDate already persisted, so the next boot's firstBoot check
    incorrectly skipped straight to Main with a default name instead of
    returning to the birth screen.
    Also swaps the Main view's weather glyph and battery icon positions so the
    battery sits flush in the top-right corner.
    [main.cpp]
2026-07-29 Skip the interactive birth/naming flow when DEV_MODE_SKIP_GROWTH is on
    Auto-names the marmot "Marmot" instead, so testing Adult-only content
    doesn't require clicking through naming via the physical buttons on
    every fresh boot/reset.
    [main.cpp]
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2026-07-30 Rework the minigames: real art, a curiosity stat, and playable stakes
    Follow-up to the minigames view, driven by playing it on hardware. The
    roster settled as Snack Hunt, Marmot Says, Forest Memory, Burrow Maze and
    Species Quiz; Burrow Hunt (a shell game), Scree Run (a lane dodger) and
    Close Up (a magnified species photo) were all built and cut, for reasons
    now recorded in CLAUDE.md so they don't get re-proposed.
    Curiosity is a real stat. It was a pure function of the weather while
    sitting as a fourth bar among three you can affect, so "how do I raise
    it?" had no answer. It now persists, decays on its own slower clock, and
    is fed by the species games and by Discovery events; the weather ter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
    [config.h, main.cpp]
2026-07-30 Give runs room to think, drop no-op unlock screens, let Marmot Says be won
    Three gaps from playing the shipping build:
    Idle sleep stretches from two minutes to five while a run is in progress.
    Minigame state is RAM-only, so dropping into deep sleep mid-run destroyed
    it -- and Forest Memory and Burrow Maze are precisely the games that ask
    the player to stop and think.
    Snack Hunt and Marmot Says no longer get unlock reveals. They're
    available from birth, so the screen announced something that was never
    locked, on the one boot that already runs a birth reveal and a naming
    flow.
    Marmot Says is now winnable at 25 calls. The sequence capped at MAX_LEN
    and then replayed the same length forever,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
    [config.h, main.cpp]
2026-07-30 Skip the winter-stash screen for a marmot under a week old
    Powering a fresh device on in December put a full-screen 'you didn't
    stockpile for winter' ceremony between the naming screen and the marmot's
    own home view, aimed at a marmot minutes old. The year is now settled
    silently below WINTER_TOO_YOUNG_DAYS, so it still won't fire twice in one
    December and next winter resolves normally.
    Distinct from WINTER_GRACE_DAYS, which waives the penalty but keeps the
    screen -- a marmot born in mid-October did have a season, just a short
    one, and deserves to hear about it.
    [config.h, main.cpp]
2026-08-01 Fix WiFi association, hide locked minigames, keep naming awake
    WiFi never associated: at the default 20dBm TX power this board fails
    auth against any AP (confirmed against both the house network and a phone
    hotspot at -40dBm) with correct credentials, which also left the clock
    stuck at epoch since NTP never ran. Scanning kept working throughout,
    because that only needs the receive path. Drop to 8.5dBm and it
    associates in ~1.6s.
    WiFi.setTxPower() silently no-ops before the STA is started, so
    esp_wifi_start() has to come first -- the readback is logged now, since a
    20.00 there means the ordering broke rather than the network.
    Also:
    - Locked minigames no longer appear on the menu at all; row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
    [main.cpp]
2026-08-01 Fix four review findings: hunger, decay stage, name length, reset
    Hunger is derived from lastFed -- evaluate() recomputes it outright -- so
    three places that assigned to s.hunger were writing values discarded on
    the next line. Snack Hunt's food reward and TrailMishap's hunger penalty
    both did nothing, and feedForaged()'s -25 was masked by its own
    lastFed = now. Adds creature::shiftHunger(), which moves lastFed instead,
    and routes the reward and the penalty through it; eating stays a full
    refill, which is what setting lastFed already meant.
    buildContext() evaluated decay before computing the stage, so ctx.stage
    was still 0 (= Baby) and every marmot aged at the Baby rate no matter how
    grown i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
    [main.cpp]
2026-08-01 Zero hunger when lastFed is at or ahead of now
    agingHunger() bailed out on now <= lastFed and left s.hunger holding its
    previous value. shiftHunger() clamps lastFed to now whenever a negative
    delta overshoots -- a good Snack Hunt haul on an already-fed marmot -- so
    the reward left a stale, higher hunger reading on screen until the next
    evaluate() a second later. Also covers a clock that moves backwards.
2026-08-01 Hold the wake pins down through deep sleep
    pinMode(INPUT_PULLDOWN) configures the digital IO-mux pull, and that block
    is powered down in deep sleep -- so LEFT/RIGHT/ENTER floated while ext1 was
    armed on ANY_HIGH. Body capacitance from picking the device up was enough to
    trip one, waking it a second or two after it slept and burning a full WiFi
    attempt plus a panel refresh each time. rtc_gpio_pulldown_en() holds them
    down for real.
    setup() now logs the wake cause and, for ext1, the pin mask, so a wake nobody
    asked for can be told apart from a power glitch.
    [main.cpp]
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2026-08-02 Remove dead netOk field and unreachable event preview case
    AppContext::netOk survived only inside the unset-clock branch after the
    radio moved to pre-sleep, and nothing ever read it -- it reported false even
    when online. eventEffectPreview()'s ForagingFind case was unreachable too:
    that screen shows how to settle the find instead of an effect line, so the
    only call site is the non-find branch. It also carried a "Hunger -20" string
    that stopped being true when the hunger fix landed.
    [main.cpp]
2026-08-02 Fix weather, which had never worked, and show a cold boot doing something
    wttr.in replies chunked. http.getStream() doesn't de-chunk, so ArduinoJson
    was parsing chunk-size lines into an empty document -- and returning no parse
    error while doing it, so fetchWeather() failed silently on every call since
    the feature was written. Confirmed on hardware ("no current_condition, doc 0
    bytes, len -1"); useHTTP10(true) gets a plain Content-Length body and the
    cache now populates. The Status weather line, the post-rain mushroom bonus in
    the Foraging ranking, and Mood::Excited-from-good-foraging were all dead
    until now.
    Three of fetchWeather()'s exits returned invalid without logging, which is
    why a br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
    [main.cpp]
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2026-08-02 Thin out the comments in the headers
    config.h was 68% comment, mostly dev-flag essays reproduced almost verbatim
    in CLAUDE.md's dev-flags section; the flags are now one line each with a
    pointer there. Same treatment for the decay/death/growth constants, which
    each carried a paragraph restating what the name already says.
    model.h and creature.h: dropped restatements of the code and rationale that
    lives in CLAUDE.md, keeping the parts that would cause a bug if missed --
    why `named` is separate from birthDate, why Minigames is the leftmost view,
    that checkDeath()'s return is terminal.
    minigames.h: trimmed the file header and the Burrow Maze essays, whose long
    forms are all in CLAUDE.md.
    conf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
    [config.h]
2026-08-02 Right-align the battery percentage against its icon
    The text was left-anchored at a fixed x, so the gap to the icon drifted with
    digit count -- 6px at "100%", 12px at "85%" -- and shifted as the battery
    drained. Measuring the string and right-aligning it holds the gap constant.
    Settings had the same bug with a wider gap, so both now go through one
    drawBatteryWithPercent() helper.
2026-08-02 Make the battery readout mean something
    The gauge mapped 3.3-4.2V linearly, but a LiPo sits between 3.7 and 3.9V for
    most of its capacity -- so 3.9V read as 67% when the cell was closer to 55%,
    and 3.7V read 44% with the cell nearly flat. That's how a marmot showing
    "67%" died with no warning. Replaced with a piecewise curve.
    The 2x200k divider also leaves ~100k of source impedance at the tap, an order
    of magnitude above what the ESP32 ADC wants, so a single conversion reads low:
    the sample-and-hold can't charge inside one sampling window. Now oversamples
    16 reads with the first discarded.
    Logs volts and percent each wake so the reading can be checked against a
    multimeter on the cell -- an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
    [config.h, main.cpp]
2026-08-02 Seed the clock from NVS instead of waiting on NTP at boot
    A power-cycle resets the RTC to 1970, which forced a blocking sync at wake
    and a "Setting the clock" screen to cover it. Both are gone: the clock is
    banked to NVS every sleep and seeded back on a cold boot, so a power-cycle is
    as quick as any other wake. The time is behind by however long the device was
    off, and the next pre-sleep refresh corrects it.
    The point isn't just the screen -- an unset clock corrupts everything derived
    from time (hunger freezes on the "never fed" sentinel, the feed streak counts
    every feed as a new day), so a plausible-but-stale clock is strictly better
    than 1970. Falls back to a sane floor if nothing was ev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
    [main.cpp]
2026-08-02 Add boot forensics and stop USB serial blocking without a host
    Serial is the USB port here, so with nothing attached every write waits on
    its TX timeout; setTxTimeoutMs(0) drops them instead. Did not fix the
    on-battery hang on its own.
    Each boot also banks its reset reason to NVS, since nothing can be watched
    over serial while the device runs on battery. Both are diagnostics for that
    hang and should come out once it's understood.
    [main.cpp]
2026-08-02 Add a low-battery cutoff and strip the diagnostic scaffolding
    Nothing stopped the device running its cell flat -- batteryPercent was only
    ever rendered. It now parks below BATT_CUTOFF_VOLTS: draws a "charge me"
    screen and deep sleeps with no wake source, so nothing can wake it to drain
    further. Checked before the panel and radio, which are what finish a weak
    cell off. The header also flags LOW at or below 15%.
    Removes the boot counters, stage marks, press/sleep counters, USB-presence
    history and the panel busy-timeout counter. They were built to chase an
    on-battery failure that turned out to be the board's battery-to-rail path,
    and they wrote to NVS on every boot.
    Kept: CORE_DEBUG_LEVEL=0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
    [config.h, main.cpp]
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2026-08-16 Recover from a flat cell instead of parking forever
    The battery cutoff deep-slept with no wake source armed, so charging could
    not revive it -- only a RESET tap, which with the power switch gone was a
    one-way trip. It now arms the buttons plus a 10-minute recheck and re-reads
    on each wake, and the check runs before display::begin() so a still-flat
    recheck costs one ADC read instead of a panel init.
    The reading itself was untrustworthy: a broken D5 wire left GPIO6 floating,
    which reads low and steady and is indistinguishable from a dead battery.
    readBatteryVolts() now takes a median with a settling gap, the cutoff
    confirms a low reading before parking, and anything under
    BATT_SENSE_FAULT_VOL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
    [config.h, main.cpp]
2026-08-16 Ask for the power combo once per device, and draw the cloud as an outline
    The combo gate hung off RTC memory, so every flash, RESET tap and brownout
    landed parked and demanded LEFT+RIGHT again. It now keys off a persisted
    poweredOn flag: only a genuine first-ever power-up parks. Power Off still
    needs the combo to come back, and Reset Game preserves the flag the same way
    it preserves the WiFi list.
    The weather cloud was a solid silhouette, which read as a blob next to the
    hairline sun and battery. Now it is a true outline -- only each lobe's top
    arc, so nothing strokes through the interior, plus the apex pixel that
    drawCircleHelper omits.
    [main.cpp]
2026-08-16 Trace the weather cloud as a bitmap outline
    Stroked arcs gave a peaked, walled shape that read as a house, and the
    solid version read as a blob. The outline is now the traced boundary of a
    union of lobes -- one closed contour by construction, with no internal
    strokes and none of drawCircleHelper's missing cardinal points.
    Also document the power combo and the battery-sense handling in CLAUDE.md.
